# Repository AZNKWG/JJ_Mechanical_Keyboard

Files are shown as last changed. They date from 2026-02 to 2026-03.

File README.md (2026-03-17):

# JJ_Mechanical_Keyboard
My repository of my 84-key mechanical keyboard.

This is my repository for an 84-key mechanical keyboard that I can use in my daily life. The reason for making this exact type of keyboard is so that it is custom to me, and because the format of it allows me to add custom changes to it to be in a more of a style of a gamer. It has a rotary encoder as a volume knob so that it is not going to be annoying to change the volume.

## CAD:



## KiCAD PCB:




## BOM:



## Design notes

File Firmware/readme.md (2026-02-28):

# mechkeyboard

mechkeyboard

*A short description of the keyboard/project*

* Keyboard Maintainer: [AZNKWG](https://github.com/AZNKWG)
* Hardware Supported: *The PCBs, controllers supported*
* Hardware Availability: *Links to where you can find this hardware*

Make example for this keyboard (after setting up your build environment):

    make mechkeyboard:default

Flashing example for this keyboard:

    make mechkeyboard:default:flash

See the [build environment setup](https://docs.qmk.fm/#/getting_started_build_tools) and the [make instructions](https://docs.qmk.fm/#/getting_started_make_guide) for more information. Brand new to QMK? Start with our [Complete Newbs Guide](https://docs.qmk.fm/#/newbs).

## Bootloader

Enter the bootloader in 3 ways:

* **Bootmagic reset**: Hold down the key at (0,0) in the matrix (usually the top left key or Escape) and plug in the keyboard
* **Physical reset button**: Briefly press the button on the back of the PCB - some may have pads you must short instead
* **Keycode in layout**: Press the key mapped to `QK_BOOT` if it is available

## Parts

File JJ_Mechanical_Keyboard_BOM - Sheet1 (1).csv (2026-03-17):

Product Name | Product Amount | Product Cost($) | Total Cost($) | Running Total($) | Product Link
1N4148 Diodes (100 Pack) | 1 | 4.39 | 4.39 | $4.65 | https://www.amazon.com/100pcs-High-Speed-Switching-DO-204AH-Package/dp/B081JKJM6N
Gateron Jade Series Brown Switch set (90 Pack) | 1 | 19.59 | 19.59 | $25.42 | Gateron G Pro 3.0 Blue Switches for Mechanical Keyboard,3-Pin 60gf Clicky/Pre-Lubed/Pin-Enhanced Switches(90pcs,Blue): Amazon.com: Industrial & Scientific
Pro Micro RP2040 | 1 | 11.96 | 11.96 | $38.10 | https://www.aliexpress.us/item/3256807101545498.html?curPageLogUid=RK6kaHcGH9yr
EC11 Rotary Encoders (5 Pack) | 1 | 1.86 | 1.86 | $40.07 | https://www.aliexpress.us/item/3256808479535031.html
Durock Stabilizers V2 TKL Kit | 1 | 11.99 | 11.99 | $52.78 | https://www.amazon.com/GATERON-Crystal-Stabilizer-Mechanical-Keyboard/dp/B0BZYK3X1S?adgrpid=192220645651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
84-Key Keycap Set | 1 | 17.99 | 17.99 | $71.85 | Amazon.com: Womier Keycaps, Lusterfly Jelly Keycaps White 60 75 100 Percent, Crystal Shine Through Custom Key caps Set, 118 Keys OEM Profile for 61/68/84/87/98/100 Cherry Gateron MX Mechanical (Backlit White) : Electronics
Keyboard PCB (QTY 5) | 1 | 15.54 | 15.54 | $88.32 | https://cart.jlcpcb.com/quote?spm=jlcpcb.Public.2006
USB-C Cable | 1 | 8.95 | 8.95 | $97.27 | https://www.amazon.com/Keyboard-Double-Sleeved-Mechanical-Detachable-Aviator/dp/B09F5YBH6Z
 |  |  | Total($) | 92.27
 |  |  | Running Total($) | 97.27

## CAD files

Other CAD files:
CAD/Final_Mech_Case.step
CAD/_Bottom_Mech_Case.80a9186b-1b8e-4eee-9d71-97a39b245fca.f3d
CAD/_Final_Mech_Case.6c4324c3-79e0-4c8c-8dc9-45cf5aad153f.f3d
CAD/_Mech_Keyboard_Design.8f437b78-3a0d-4561-b073-fda4e4e9f4ed.f3d
CAD/_Top_Mech_Case.fb088db0-0566-425f-93ac-fc1d6e48a953.f3d

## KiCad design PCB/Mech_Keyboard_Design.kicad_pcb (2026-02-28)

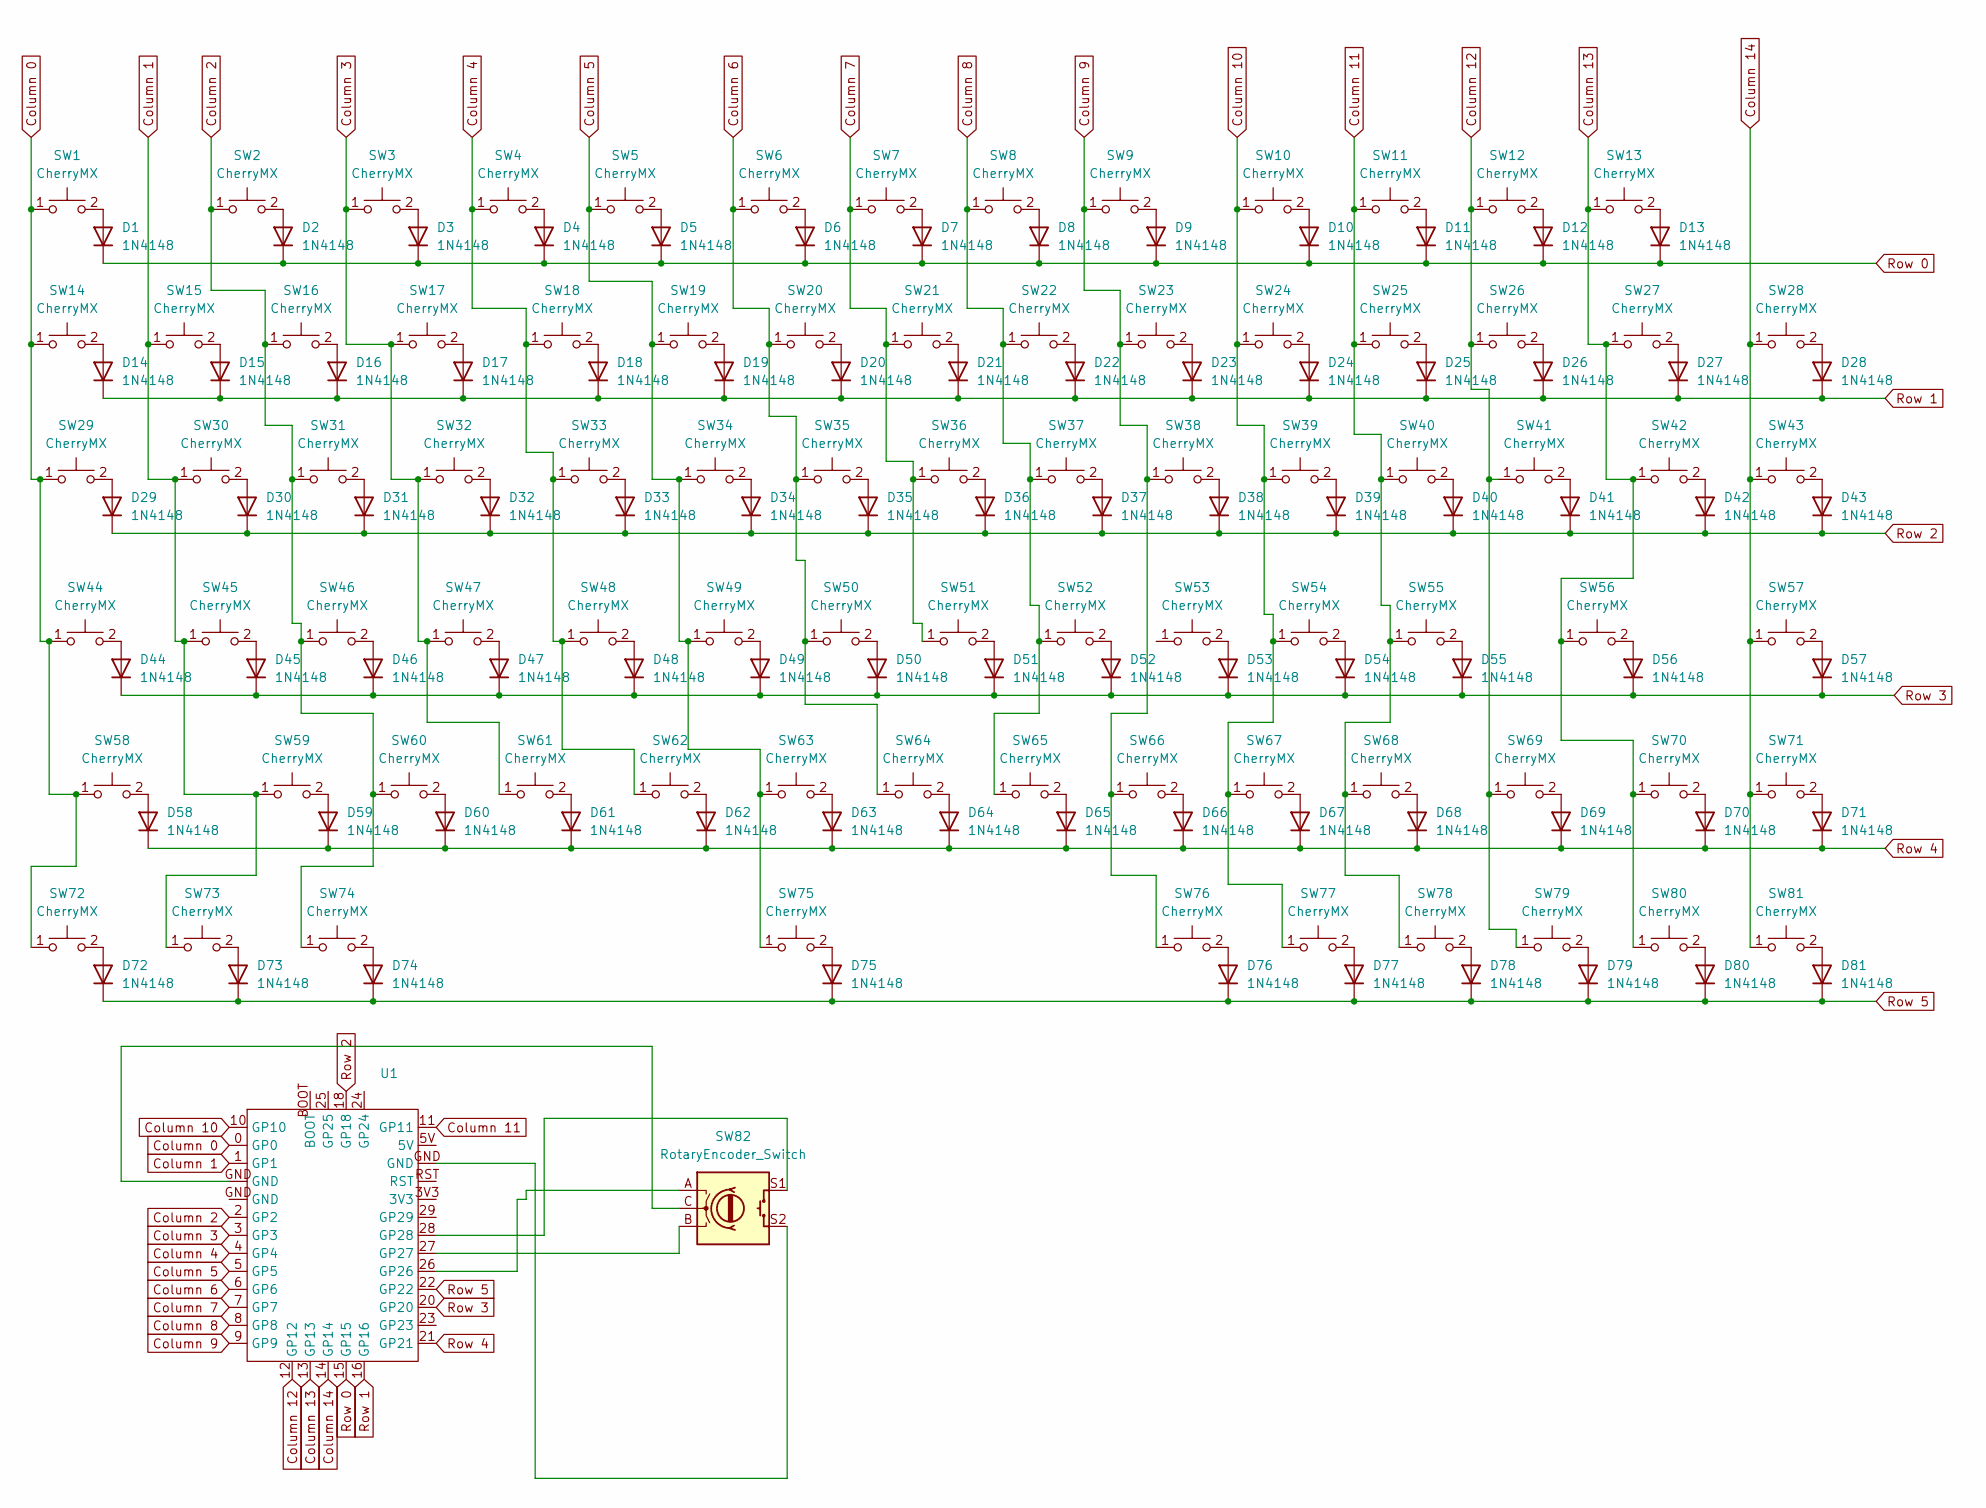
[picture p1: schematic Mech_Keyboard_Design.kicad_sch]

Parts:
D1, D2, D3, D4, D5, D6, D7, D8, D9, D10, D11, D12, D13, D14, D15, D16, D17, D18, D19, D20, D21, D22, D23, D24, D25, D26, D27, D28, D29, D30, D31, D32, D33, D34, D35, D36, D37, D38, D39, D40, D41, D42, D43, D44, D45, D46, D47, D48, D49, D50, D51, D52, D53, D54, D55, D56, D57, D58, D59, D60, D61, D62, D63, D64, D65, D66, D67, D68, D69, D70, D71, D72, D73, D74, D75, D76, D77, D78, D79, D80, D81: 1N4148; D_DO-35_SOD27_P7.62mm_Horizontal
SW1, SW2, SW3, SW4, SW5, SW6, SW7, SW8, SW9, SW10, SW11, SW12, SW13, SW14, SW15, SW16, SW17, SW18, SW19, SW20, SW21, SW22, SW23, SW24, SW25, SW26, SW28, SW30, SW31, SW32, SW33, SW34, SW35, SW36, SW37, SW38, SW39, SW40, SW41, SW43, SW45, SW46, SW47, SW48, SW49, SW50, SW51, SW52, SW53, SW54, SW55, SW57, SW59, SW60, SW61, SW62, SW63, SW64, SW65, SW66, SW67, SW68, SW70, SW71, SW76, SW77, SW78, SW79, SW80, SW81: CherryMX; SW_Cherry_MX_1.00u_PCB
SW27: CherryMX; SW_Cherry_MX_2.00u_PCB
SW29, SW42: CherryMX; SW_Cherry_MX_1.50u_PCB
SW44, SW69: CherryMX; SW_Cherry_MX_1.75u_PCB
SW56, SW58: CherryMX; SW_Cherry_MX_2.25u_PCB
SW72, SW73, SW74: CherryMX; SW_Cherry_MX_1.25u_PCB
SW75: CherryMX; SW_Cherry_MX_6.25u_PCB
SW82: RotaryEncoder_Switch; RotaryEncoder_Alps_EC11E-Switch_Vertical_H20mm
U1: pro_micro_rp2040

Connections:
Column 0: SW1.1, SW14.1, SW29.1, SW44.1, SW58.1, SW72.1, U1.0 (GP0)
Column 1: SW15.1, SW30.1, SW45.1, SW59.1, SW73.1, U1.1 (GP1)
Column 2: SW2.1, SW16.1, SW31.1, SW46.1, SW60.1, SW74.1, U1.2 (GP2)
Column 3: SW3.1, SW17.1, SW32.1, SW47.1, SW61.1, U1.3 (GP3)
Column 4: SW4.1, SW18.1, SW33.1, SW48.1, SW62.1, U1.4 (GP4)
Column 5: SW5.1, SW19.1, SW34.1, SW49.1, SW63.1, SW75.1, U1.5 (GP5)
Column 6: SW6.1, SW20.1, SW35.1, SW50.1, SW64.1, U1.6 (GP6)
Column 7: SW7.1, SW21.1, SW36.1, SW51.1, U1.7 (GP7)
Column 8: SW8.1, SW22.1, SW37.1, SW52.1, SW65.1, U1.8 (GP8)
Column 9: SW9.1, SW23.1, SW38.1, SW66.1, SW76.1, U1.9 (GP9)
Column 10: SW10.1, SW24.1, SW39.1, SW54.1, SW67.1, SW77.1, U1.10 (GP10)
Column 11: SW11.1, SW25.1, SW40.1, SW55.1, SW68.1, SW78.1, U1.11 (GP11)
Column 12: SW12.1, SW26.1, SW41.1, SW69.1, SW79.1, U1.12 (GP12)
Column 13: SW13.1, SW27.1, SW42.1, SW56.1, SW70.1, SW80.1, U1.13 (GP13)
Column 14: SW28.1, SW43.1, SW57.1, SW71.1, SW81.1, U1.14 (GP14)
unnamed: D1.2 (A), SW1.2
unnamed: D2.2 (A), SW2.2
unnamed: D3.2 (A), SW3.2
unnamed: D4.2 (A), SW4.2
unnamed: D5.2 (A), SW5.2
unnamed: D6.2 (A), SW6.2
unnamed: D7.2 (A), SW7.2
unnamed: D8.2 (A), SW8.2
unnamed: D9.2 (A), SW9.2
unnamed: D10.2 (A), SW10.2
unnamed: D11.2 (A), SW11.2
unnamed: D12.2 (A), SW12.2
unnamed: D13.2 (A), SW13.2
unnamed: D14.2 (A), SW14.2
unnamed: D15.2 (A), SW15.2
unnamed: D16.2 (A), SW16.2
unnamed: D17.2 (A), SW17.2
unnamed: D18.2 (A), SW18.2
unnamed: D19.2 (A), SW19.2
unnamed: D20.2 (A), SW20.2
unnamed: D21.2 (A), SW21.2
unnamed: D22.2 (A), SW22.2
unnamed: D23.2 (A), SW23.2
unnamed: D24.2 (A), SW24.2
unnamed: D25.2 (A), SW25.2
unnamed: D26.2 (A), SW26.2
unnamed: D27.2 (A), SW27.2
unnamed: D28.2 (A), SW28.2
unnamed: D29.2 (A), SW29.2
unnamed: D30.2 (A), SW30.2
unnamed: D31.2 (A), SW31.2
unnamed: D32.2 (A), SW32.2
unnamed: D33.2 (A), SW33.2
unnamed: D34.2 (A), SW34.2
unnamed: D35.2 (A), SW35.2
unnamed: D36.2 (A), SW36.2
unnamed: D37.2 (A), SW37.2
unnamed: D38.2 (A), SW38.2
unnamed: D39.2 (A), SW39.2
unnamed: D40.2 (A), SW40.2
unnamed: D41.2 (A), SW41.2
unnamed: D42.2 (A), SW42.2
unnamed: D43.2 (A), SW43.2
unnamed: D44.2 (A), SW44.2
unnamed: D45.2 (A), SW45.2
unnamed: D46.2 (A), SW46.2
unnamed: D47.2 (A), SW47.2
unnamed: D48.2 (A), SW48.2
unnamed: D49.2 (A), SW49.2
unnamed: D50.2 (A), SW50.2
unnamed: D51.2 (A), SW51.2
unnamed: D52.2 (A), SW52.2
unnamed: D53.2 (A), SW53.2
unnamed: D54.2 (A), SW54.2
unnamed: D55.2 (A), SW55.2
unnamed: D56.2 (A), SW56.2
unnamed: D57.2 (A), SW57.2
unnamed: D58.2 (A), SW58.2
unnamed: D59.2 (A), SW59.2
unnamed: D60.2 (A), SW60.2
unnamed: D61.2 (A), SW61.2
unnamed: D62.2 (A), SW62.2
unnamed: D63.2 (A), SW63.2
unnamed: D64.2 (A), SW64.2
unnamed: D65.2 (A), SW65.2
unnamed: D66.2 (A), SW66.2
unnamed: D67.2 (A), SW67.2
unnamed: D68.2 (A), SW68.2
unnamed: D69.2 (A), SW69.2
unnamed: D70.2 (A), SW70.2
unnamed: D71.2 (A), SW71.2
unnamed: D72.2 (A), SW72.2
unnamed: D73.2 (A), SW73.2
unnamed: D74.2 (A), SW74.2
unnamed: D75.2 (A), SW75.2
unnamed: D76.2 (A), SW76.2
unnamed: D77.2 (A), SW77.2
unnamed: D78.2 (A), SW78.2
unnamed: D79.2 (A), SW79.2
unnamed: D80.2 (A), SW80.2
unnamed: D81.2 (A), SW81.2
unnamed: SW82.A, U1.26 (GP26)
unnamed: SW82.B, U1.27 (GP27)
unnamed: SW82.S1, U1.28 (GP28)
Row 0: D1.1 (K), D2.1 (K), D3.1 (K), D4.1 (K), D5.1 (K), D6.1 (K), D7.1 (K), D8.1 (K), D9.1 (K), D10.1 (K), D11.1 (K), D12.1 (K), D13.1 (K), U1.15 (GP15)
Row 1: D14.1 (K), D15.1 (K), D16.1 (K), D17.1 (K), D18.1 (K), D19.1 (K), D20.1 (K), D21.1 (K), D22.1 (K), D23.1 (K), D24.1 (K), D25.1 (K), D26.1 (K), D27.1 (K), D28.1 (K), U1.16 (GP16)
Row 2: D29.1 (K), D30.1 (K), D31.1 (K), D32.1 (K), D33.1 (K), D34.1 (K), D35.1 (K), D36.1 (K), D37.1 (K), D38.1 (K), D39.1 (K), D40.1 (K), D41.1 (K), D42.1 (K), D43.1 (K), U1.18 (GP18)
Row 3: D44.1 (K), D45.1 (K), D46.1 (K), D47.1 (K), D48.1 (K), D49.1 (K), D50.1 (K), D51.1 (K), D52.1 (K), D53.1 (K), D54.1 (K), D55.1 (K), D56.1 (K), D57.1 (K), U1.20 (GP20)
Row 4: D58.1 (K), D59.1 (K), D60.1 (K), D61.1 (K), D62.1 (K), D63.1 (K), D64.1 (K), D65.1 (K), D66.1 (K), D67.1 (K), D68.1 (K), D69.1 (K), D70.1 (K), D71.1 (K), U1.21 (GP21)
Row 5: D72.1 (K), D73.1 (K), D74.1 (K), D75.1 (K), D76.1 (K), D77.1 (K), D78.1 (K), D79.1 (K), D80.1 (K), D81.1 (K), U1.22 (GP22)

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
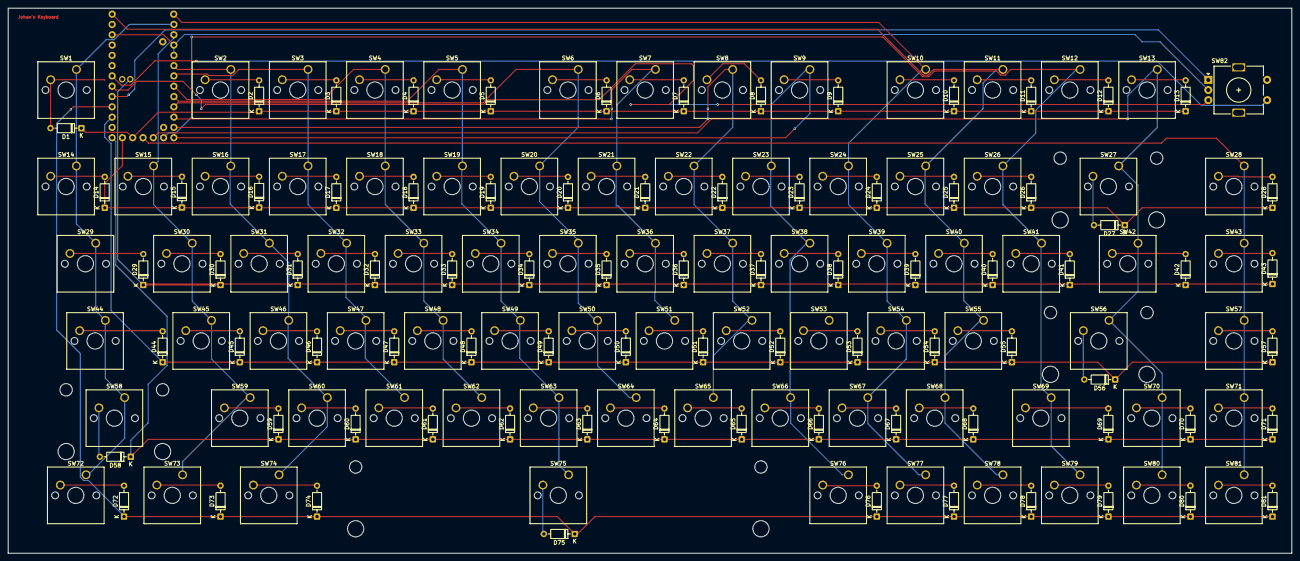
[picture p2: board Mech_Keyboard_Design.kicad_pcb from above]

Board: 2 copper layers, 316.7 x 134.5 mm, 164 parts (1 on the bottom side), 106 nets.
